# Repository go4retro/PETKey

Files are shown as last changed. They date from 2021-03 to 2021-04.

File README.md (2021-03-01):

# Commodore VIC/64 to PET/CBM Keyboard Adapter

## Hardware License

Copyright (C) 2021 Jim Brain and RETRO Innovations

These files are free designs; you can redistribute them and/or modify
them under the terms of the Creative Commons Attribution-ShareAlike 
4.0 International License.

You should have received a copy of the license along with this
work. If not, see <http://creativecommons.org/licenses/by-sa/4.0/>.

These files are distributed in the hope that they will be useful,
but WITHOUT ANY WARRANTY; without even the implied warranty of
MERCHANTABILITY or FITNESS FOR A PARTICULAR PURPOSE.  See the
license for more details.

## Software License

Copyright (C) 2021 Jim Brain and RETRO Innovations

These files are free designs; you can redistribute them and/or modify
them under the terms of the GNU General Public License, version 2 as 
published by the Free Software Foundation.

These files are distributed in the hope that they will be useful,
but WITHOUT ANY WARRANTY; without even the implied warranty of
MERCHANTABILITY or FITNESS FOR A PARTICULAR PURPOSE.  See the
GNU General Public License for more details.

You should have received a copy of the GNU General Public License along
with these files; if not, write to the Free Software Foundation, Inc.,
51 Franklin Street, Fifth Floor, Boston, MA 02110-1301 USA.

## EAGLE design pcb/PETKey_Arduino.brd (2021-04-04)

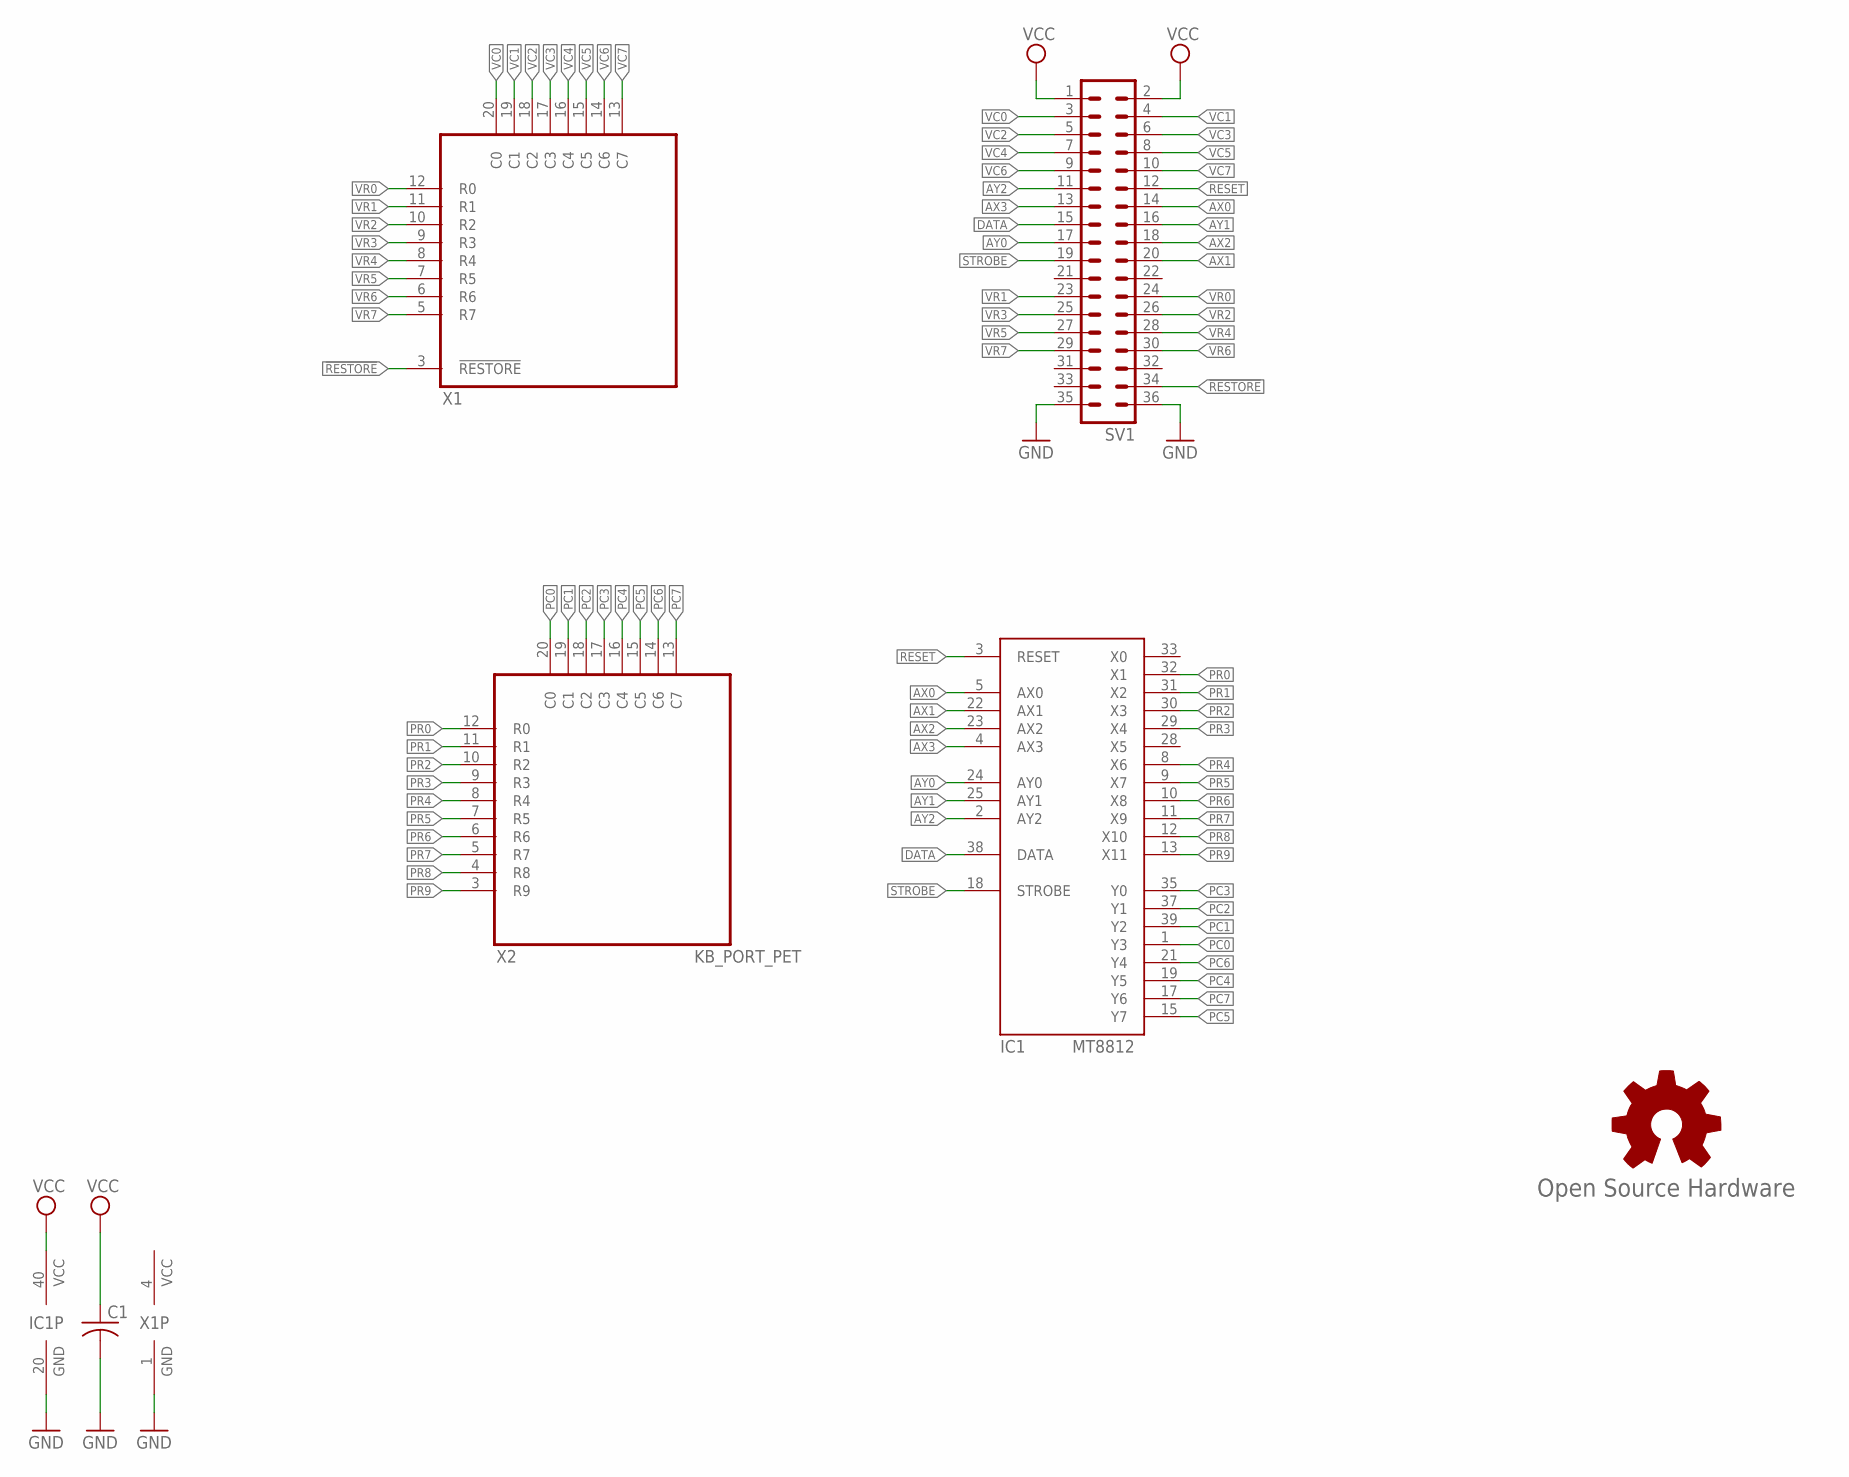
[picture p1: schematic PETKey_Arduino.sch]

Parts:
C1: C-US025-025X050; C025-025X050
GOLD_ORB_SM1: Open Source Hardware; OSHW_8MM
IC1: MT8812; DIP40
SV1: MA18-2
X1: KB_PORT_VIC/64; MA20-1_KEYED
X2: KB_PORT_PET; MA20-1_KEYED

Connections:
!RESTORE: SV1.34, X1.3 (!RESTORE)
AX0: IC1.5 (AX0), SV1.14
AX1: IC1.22 (AX1), SV1.20
AX2: IC1.23 (AX2), SV1.18
AX3: IC1.4 (AX3), SV1.13
AY0: IC1.24 (AY0), SV1.17
AY1: IC1.25 (AY1), SV1.16
AY2: IC1.2 (AY2), SV1.11
DATA: IC1.38 (DATA), SV1.15
GND: C1.2, IC1.20 (GND), SV1.35, SV1.36, X1.1 (GND), X2.1 (GND)
PC0: IC1.1 (Y3), X2.20 (C0)
PC1: IC1.39 (Y2), X2.19 (C1)
PC2: IC1.37 (Y1), X2.18 (C2)
PC3: IC1.35 (Y0), X2.17 (C3)
PC4: IC1.19 (Y5), X2.16 (C4)
PC5: IC1.15 (Y7), X2.15 (C5)
PC6: IC1.21 (Y4), X2.14 (C6)
PC7: IC1.17 (Y6), X2.13 (C7)
PR0: IC1.32 (X1), X2.12 (R0)
PR1: IC1.31 (X2), X2.11 (R1)
PR2: IC1.30 (X3), X2.10 (R2)
PR3: IC1.29 (X4), X2.9 (R3)
PR4: IC1.8 (X6), X2.8 (R4)
PR5: IC1.9 (X7), X2.7 (R5)
PR6: IC1.10 (X8), X2.6 (R6)
PR7: IC1.11 (X9), X2.5 (R7)
PR8: IC1.12 (X10), X2.4 (R8)
PR9: IC1.13 (X11), X2.3 (R9)
RESET: IC1.3 (RESET), SV1.12
STROBE: IC1.18 (STROBE), SV1.19
VC0: SV1.3, X1.20 (C0)
VC1: SV1.4, X1.19 (C1)
VC2: SV1.5, X1.18 (C2)
VC3: SV1.6, X1.17 (C3)
VC4: SV1.7, X1.16 (C4)
VC5: SV1.8, X1.15 (C5)
VC6: SV1.9, X1.14 (C6)
VC7: SV1.10, X1.13 (C7)
VCC: C1.1, IC1.40 (VCC), SV1.1, SV1.2, X1.4 (VCC)
VR0: SV1.24, X1.12 (R0)
VR1: SV1.23, X1.11 (R1)
VR2: SV1.26, X1.10 (R2)
VR3: SV1.25, X1.9 (R3)
VR4: SV1.28, X1.8 (R4)
VR5: SV1.27, X1.7 (R5)
VR6: SV1.30, X1.6 (R6)
VR7: SV1.29, X1.5 (R7)

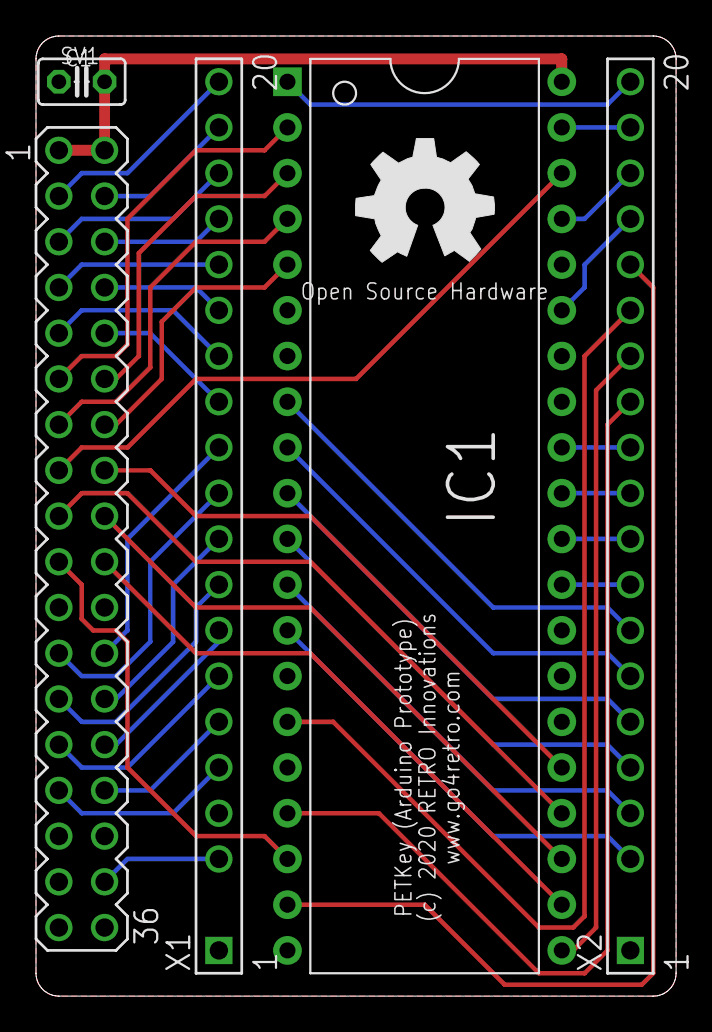
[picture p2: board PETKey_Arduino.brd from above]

Board: 2 copper layers, 35.6 x 53.3 mm, 6 parts (0 on the bottom side), 47 nets.

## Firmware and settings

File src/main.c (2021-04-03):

/*
 *  PETKey - VIC/64 to PET keyboard adapter
 *  Copyright (C) 2021 Jim Brain and RETRO Innovations <go4retro@go4retro.com>
 *
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
 *  main.c: Main application
 */

#include <inttypes.h>
#include <avr/interrupt.h>
#include <util/delay.h>

#include "config.h"

#include "debug.h"
#include "uart.h"
#include "vkb.h"

ISR(SCAN_TIMER) {
  vkb_irq();
}

void main( void ) {
  debug_init();
  timer_init();
  vkb_init();
  sei();
  vkb_scan();
}

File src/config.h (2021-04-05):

/*
 *  PETKey - VIC/64 to PET keyboard adapter
 *  Copyright (C) 2021 Jim Brain and RETRO Innovations <go4retro@go4retro.com>
 *
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
 *  config.h: User-configurable options to simplify hardware changes and/or
 *             reduce the code/ram requirements of the code.
 */

#ifndef CONFIG_H
#define CONFIG_H

#define FLASH_MEM_DATA  1

#include <avr/io.h>
#include <util/delay.h>

#ifndef ARDUINO
 #include "autoconf.h"
#else

// Debug to serial
#define CONFIG_UART_DEBUG
//#define CONFIG_UART_DEBUG_SW
#define CONFIG_UART_DEBUG_RATE    115200
#define CONFIG_UART_DEBUG_FLUSH
#define CONFIG_UART_BUF_SHIFT     8

#endif

#ifndef TRUE
#define FALSE                 0
#define TRUE                  (!FALSE)
#endif

//#define ENABLE_UART0
// log2 of the UART buffer size, i.e. 6 for 64, 7 for 128, 8 for 256 etc.
//#define UART0_TX_BUFFER_SHIFT  6
//#define UART0_RX_BUFFER_SHIFT  6
//#define UART0_BAUDRATE CONFIG_UART_BAUDRATE

#if CONFIG_HARDWARE_VARIANT == 1
/* ---------- Hardware configuration: PETKey Final ---------- */

#define KB_ROW_HI_OUT       PORTB
#define KB_ROW_HI_IN        PINB
#define KB_ROW_HI_DDR       DDRB
#define KB_ROW_LO_OUT       PORTC
#define KB_ROW_LO_IN        PINC
#define KB_ROW_LO_DDR       DDRC
#define KB_COL_OUT          PORTA
#define KB_COL_IN           PINA
#define KB_COL_DDR          DDRA

#define XPT_PORT_DATA_OUT   PORTB
#define XPT_DDR_DATA        DDRB
#define XPT_PORT_STROBE_OUT PORTD
#define XPT_DDR_STROBE      DDRD

#define XPT_PIN_STROBE      (1<<PIN6)

#elif CONFIG_HARDWARE_VARIANT == 2 || defined ARDUINO_AVR_MEGA2560
/* ---------- Hardware configuration: PETKey Arduino ---------- */

#define SCAN_TIMER          TIMER0_COMPA_vect

static inline void timer_init(void) {
  // need to scan 120 * 8 times a sec
  TCCR0A = _BV(WGM01);            // CTC mode
  TCCR0B = _BV(CS02) | _BV(CS00); // /1024
  OCR0A = (F_CPU / 1024 / 120 / 8) - 1;
  TIMSK0 = _BV(OCIE0A);
}

// rmeove hi port.
#define KB_ROW_LO_OUT       PORTL
#define KB_ROW_LO_IN        PINL
#define KB_ROW_LO_DDR       DDRL
#define KB_COL_OUT          PORTA
#define KB_COL_IN           PINA
#define KB_COL_DDR          DDRA

#define XPT_RESET_DDR       DDRC
#define XPT_RESET_OUT       PORTC
#define XPT_RESET_PIN       PIN6

#define XPT_AX0_DDR         DDRC
#define XPT_AX0_OUT         PORTC
#define XPT_AX0_PIN         PIN4

#define XPT_AX1_DDR         DDRG
#define XPT_AX1_OUT         PORTG
#define XPT_AX1_PIN         PIN2

#define XPT_AX2_DDR         DDRC
#define XPT_AX2_OUT         PORTC
#define XPT_AX2_PIN         PIN0

#define XPT_AX3_DDR         DDRC
#define XPT_AX3_OUT         PORTC
#define XPT_AX3_PIN         PIN5

#define XPT_AY0_DDR         DDRC
#define XPT_AY0_OUT         PORTC
#define XPT_AY0_PIN         PIN1

#define XPT_AY1_DDR         DDRC
#define XPT_AY1_OUT         PORTC
#define XPT_AY1_PIN         PIN2

#define XPT_AY2_DDR         DDRC
#define XPT_AY2_OUT         PORTC
#define XPT_AY2_PIN         PIN7

#define XPT_DATA_DDR        DDRC
#define XPT_DATA_OUT        PORTC
#define XPT_DATA_PIN        PIN3

#define XPT_STROBE_DDR      DDRD
#define XPT_STROBE_OUT      PORTD
#define XPT_STROBE_PIN      PIN7

#define XPT_ROW_0           13
#define XPT_ROW_1           12
#define XPT_ROW_2           11
#define XPT_ROW_3           10
#define XPT_ROW_4           9
#define XPT_ROW_5           8
#define XPT_ROW_6           4
#define XPT_ROW_7           3
#define XPT_ROW_8           2
#define XPT_ROW_9           1

#define XPT_COL_0           6
#define XPT_COL_1           4
#define XPT_COL_2           7
#define XPT_COL_3           5
#define XPT_COL_4           0
#define XPT_COL_5           1
#define XPT_COL_6           2
#define XPT_COL_7           3


#else
#  error "CONFIG_HARDWARE_VARIANT is unset or set to an unknown value."
#endif

static inline void xpt_init(void) {
  XPT_STROBE_OUT &= ~_BV(XPT_STROBE_PIN);

  XPT_RESET_DDR |= _BV(XPT_RESET_PIN);
  XPT_AX0_DDR |= _BV(XPT_AX0_PIN);
  XPT_AX1_DDR |= _BV(XPT_AX1_PIN);
  XPT_AX2_DDR |= _BV(XPT_AX2_PIN);
  XPT_AX3_DDR |= _BV(XPT_AX3_PIN);
  XPT_AY0_DDR |= _BV(XPT_AY0_PIN);
  XPT_AY1_DDR |= _BV(XPT_AY1_PIN);
  XPT_AY2_DDR |= _BV(XPT_AY2_PIN);
  XPT_DATA_DDR |= _BV(XPT_DATA_PIN);
  XPT_STROBE_DDR |= _BV(XPT_STROBE_PIN);

  XPT_RESET_OUT |= _BV(XPT_RESET_PIN);
  _delay_us(1);
  XPT_RESET_OUT &= ~_BV(XPT_RESET_PIN);

}
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

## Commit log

2021-03-01 Initial import
    [PETKey_Arduino.brd, PETKey_Arduino.sch]
2021-03-01 Small fix to code to compile in Arduino IDE
    [config.h]
2021-04-04 Debug code added
    [PET KB Mappings.xlsx]
2021-04-04 Fix incorrect XPT mappings
    [PETKey_Arduino.brd, PETKey_Arduino.sch]
2021-04-05 Refactored mappings into tables and reworked MOD_OVERRIDE behavior
    [config.h]
2021-04-18 More case fixes

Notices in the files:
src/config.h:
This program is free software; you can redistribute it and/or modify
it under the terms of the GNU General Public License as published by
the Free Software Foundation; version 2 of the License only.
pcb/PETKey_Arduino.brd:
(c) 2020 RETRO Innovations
